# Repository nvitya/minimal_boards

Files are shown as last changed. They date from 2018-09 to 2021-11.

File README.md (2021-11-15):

# Breadboard Friendly Minimal Boards

The project on the Github: [https://github.com/nvitya/minimal_boards](https://github.com/nvitya/minimal_boards)

The boards are developed with KiCAD 5: [http://kicad.org/](http://kicad.org/)

## Board List

__Name__        | __Status__      | __Description__
----------------|-----------------|-------------------------------------------------------------
MIBO48-STM32    | Tested, OK      | For 48 pin QFP STM32 Microcontrollers (F103, F303, F070 etc)
MIBO48-STM32G4  | Tested, OK      | For 48 pin QFP STM32G4 Microcontrollers
MIBO48-XMC4     | Tested, OK      | For 48 pin QFP XMC4000 Microcontrollers
MIBO64-STM32    | Tested, OK      | For 64 pin QFP STM32 Microcontrollers (F405, F303, F070 etc)
MIBO64-ATSAM4S  | Tested, OK      | For 64 pin QFP ATSAM4SxB Microcontrollers
MIBO64-ATSAME5X | Tested, OK      | For 64 pin QFP ATSAME5xJ/ATSAMD5x Microcontrollers
MIBO20-STM32    | Tested, OK      | For the 20 pin TSSOP STM32 Microcontrollers (F030, F070, L011 etc)

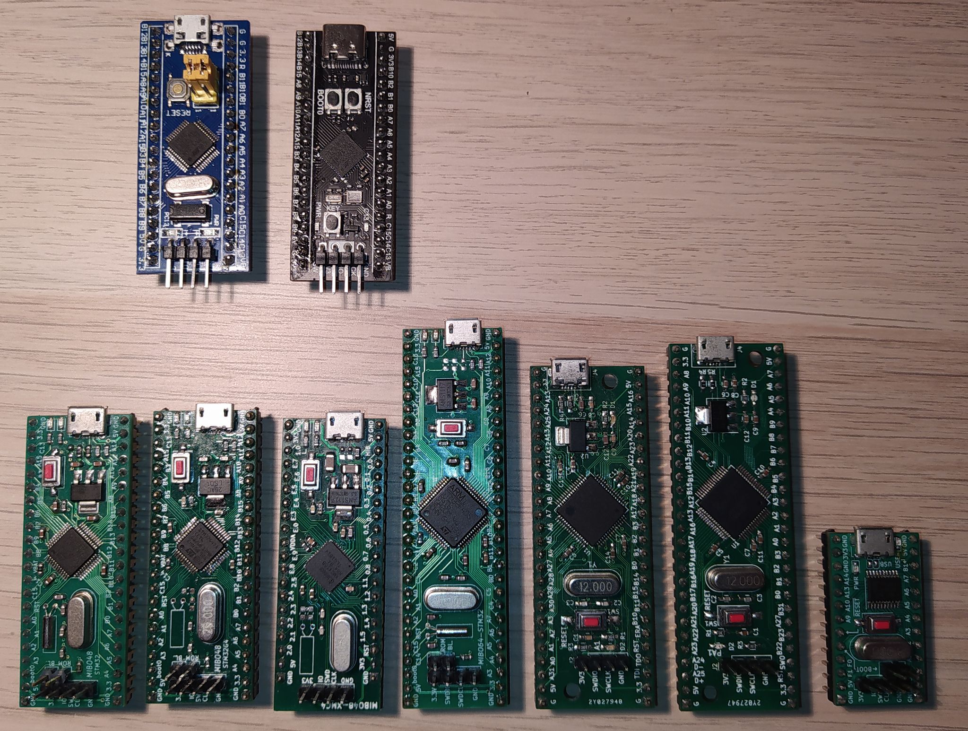
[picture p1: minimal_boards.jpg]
assembled boards


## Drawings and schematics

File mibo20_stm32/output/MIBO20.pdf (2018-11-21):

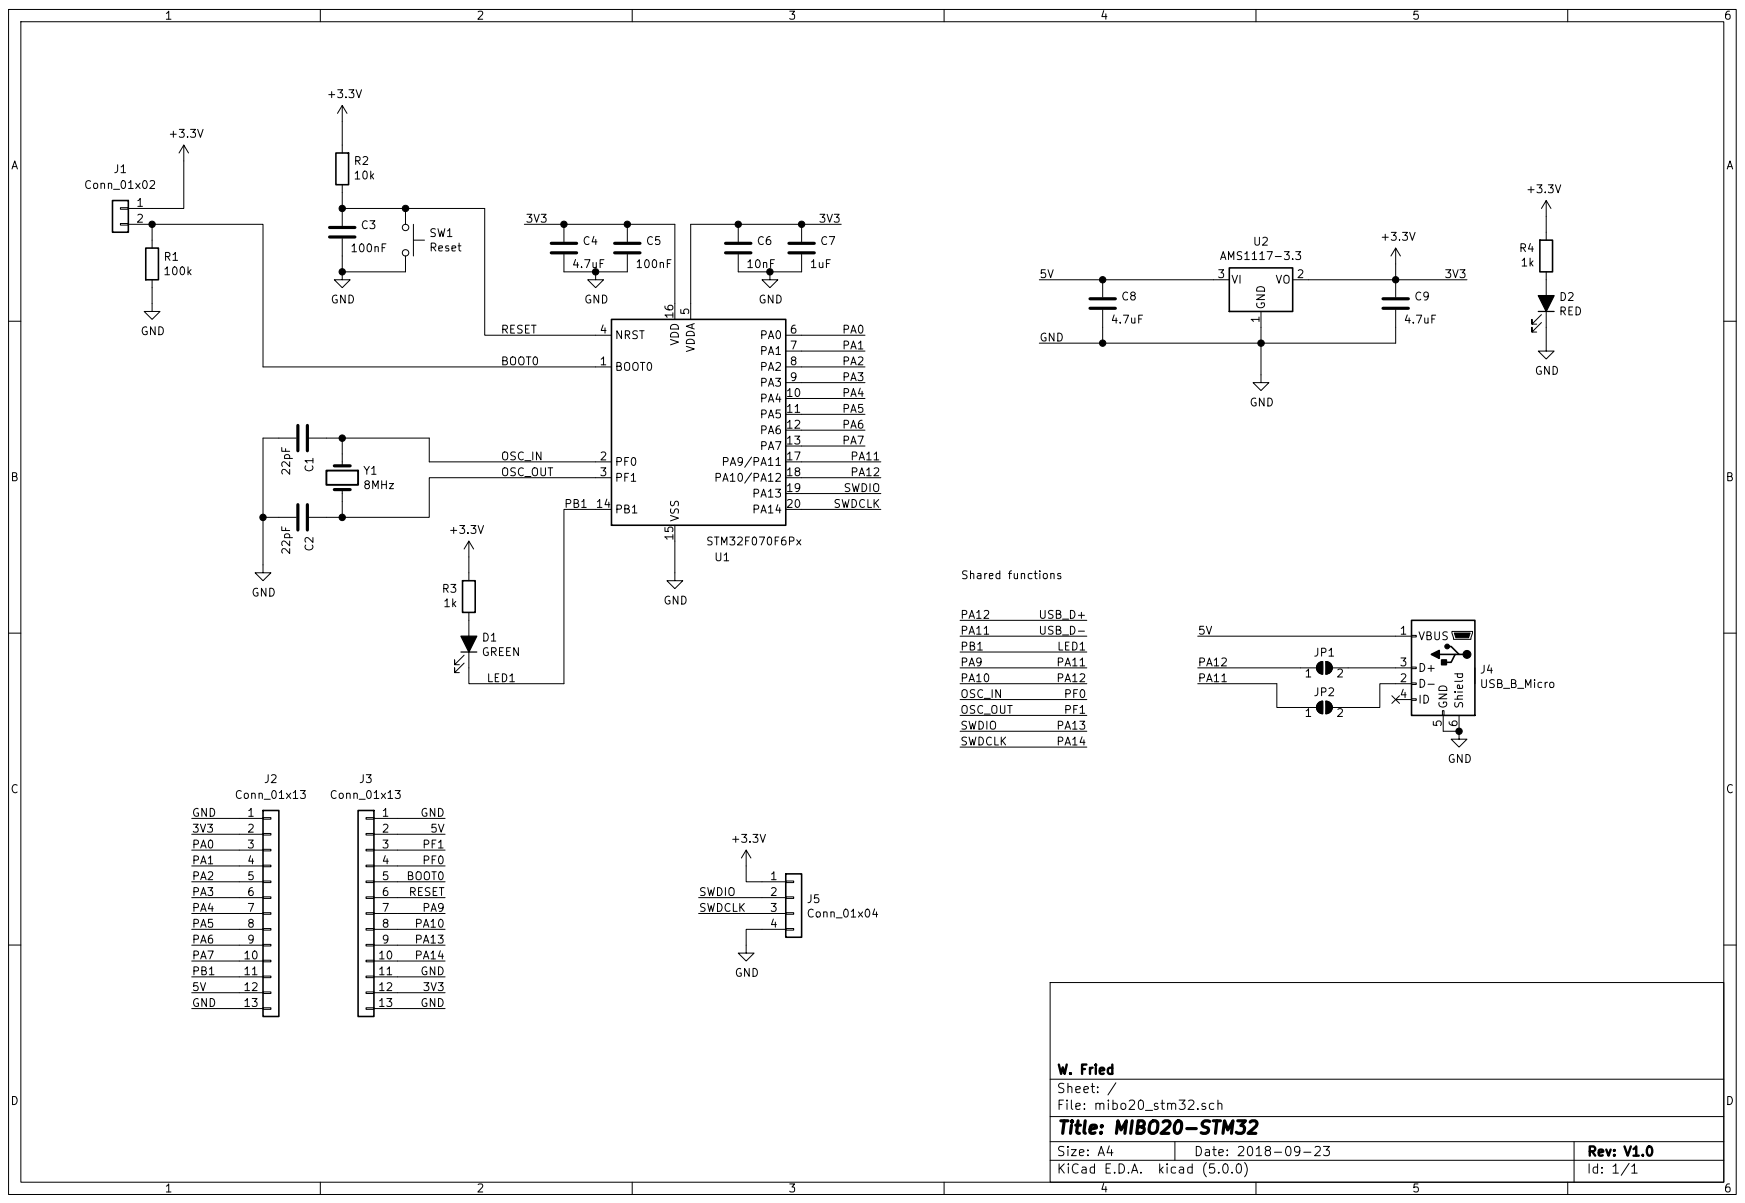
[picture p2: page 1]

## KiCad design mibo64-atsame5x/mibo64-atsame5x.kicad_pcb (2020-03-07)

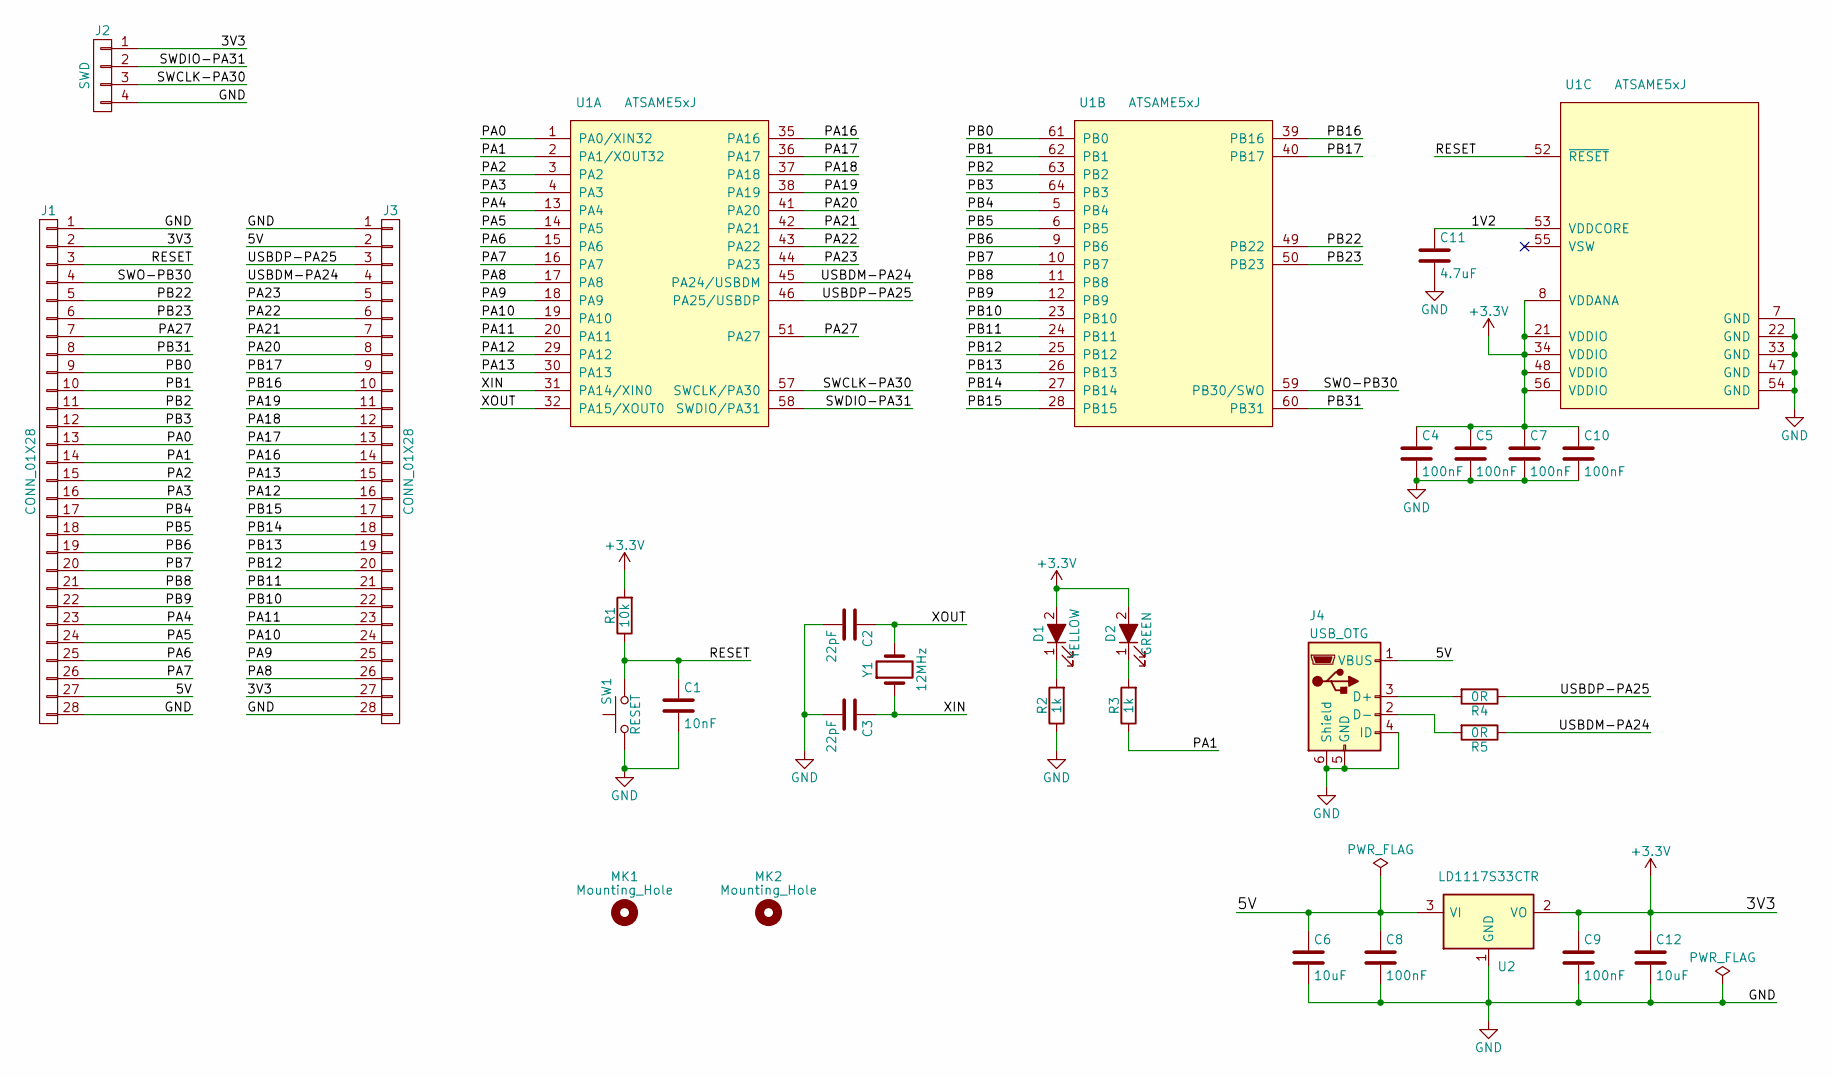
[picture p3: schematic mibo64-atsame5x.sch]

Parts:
C1: 10nF; C_0603_HandSoldering
C2, C3: 22pF; C_0603_HandSoldering
C4, C5, C7, C8, C9, C10: 100nF; C_0603_HandSoldering
C6, C12: 10uF; C_0603_HandSoldering
C11: 4.7uF; C_0603_HandSoldering
D1: YELLOW; LED_0603_HandSoldering
D2: GREEN; LED_0603_HandSoldering
J1, J3: CONN_01X28; Pin_Header_Straight_1x28_Pitch2.54mm
J2: SWD; Pin_Header_Straight_1x04_Pitch2.54mm
J4: USB_OTG; USB_Micro-B
MK1, MK2: Mounting_Hole; MountingHole_3.2mm_M3
R1: 10k; R_0603_HandSoldering
R2, R3: 1k; R_0603_HandSoldering
R4, R5: 0R; R_0603_HandSoldering
SW1: RESET; SW_SPST_FSMSM
U1: ATSAME5xJ; TQFP-64_10x10mm_Pitch0.5mm
U2: LD1117S33CTR; SOT-223
Y1: 12MHz; Crystal_HC49-4H_Vertical

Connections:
+3V3: C4.1, C5.1, C7.1, C9.1, C10.1, C12.1, D1.2 (A), D2.2 (A), J1.2, J2.1, J3.27, R1.2, U1.8 (VDDANA), U1.21 (VDDIO), U1.34 (VDDIO), U1.48 (VDDIO), U1.56 (VDDIO), U2.2 (VO)
/1V2: C11.1, U1.53 (VDDCORE)
/5V: C6.1, C8.1, J1.27, J3.2, J4.1 (VBUS), U2.3 (VI)
/PA0: J1.13, U1.1 (PA0/XIN32)
/PA1: J1.14, R3.1, U1.2 (PA1/XOUT32)
/PA2: J1.15, U1.3 (PA2)
/PA3: J1.16, U1.4 (PA3)
/PA4: J1.23, U1.13 (PA4)
/PA5: J1.24, U1.14 (PA5)
/PA6: J1.25, U1.15 (PA6)
/PA7: J1.26, U1.16 (PA7)
/PA8: J3.26, U1.17 (PA8)
/PA9: J3.25, U1.18 (PA9)
/PA10: J3.24, U1.19 (PA10)
/PA11: J3.23, U1.20 (PA11)
/PA12: J3.16, U1.29 (PA12)
/PA13: J3.15, U1.30 (PA13)
/PA16: J3.14, U1.35 (PA16)
/PA17: J3.13, U1.36 (PA17)
/PA18: J3.12, U1.37 (PA18)
/PA19: J3.11, U1.38 (PA19)
/PA20: J3.8, U1.41 (PA20)
/PA21: J3.7, U1.42 (PA21)
/PA22: J3.6, U1.43 (PA22)
/PA23: J3.5, U1.44 (PA23)
/PA27: J1.7, U1.51 (PA27)
/PB0: J1.9, U1.61 (PB0)
/PB1: J1.10, U1.62 (PB1)
/PB2: J1.11, U1.63 (PB2)
/PB3: J1.12, U1.64 (PB3)
/PB4: J1.17, U1.5 (PB4)
/PB5: J1.18, U1.6 (PB5)
/PB6: J1.19, U1.9 (PB6)
/PB7: J1.20, U1.10 (PB7)
/PB8: J1.21, U1.11 (PB8)
/PB9: J1.22, U1.12 (PB9)
/PB10: J3.22, U1.23 (PB10)
/PB11: J3.21, U1.24 (PB11)
/PB12: J3.20, U1.25 (PB12)
/PB13: J3.19, U1.26 (PB13)
/PB14: J3.18, U1.27 (PB14)
/PB15: J3.17, U1.28 (PB15)
/PB16: J3.10, U1.39 (PB16)
/PB17: J3.9, U1.40 (PB17)
/PB22: J1.5, U1.49 (PB22)
/PB23: J1.6, U1.50 (PB23)
/PB31: J1.8, U1.60 (PB31)
/RESET: C1.1, J1.3, R1.1, SW1.2, U1.52 (~RESET)
/SWCLK-PA30: J2.3, U1.57 (SWCLK/PA30)
/SWDIO-PA31: J2.2, U1.58 (SWDIO/PA31)
/SWO-PB30: J1.4, U1.59 (PB30/SWO)
/USBDM-PA24: J3.4, R5.1, U1.45 (PA24/USBDM)
/USBDP-PA25: J3.3, R4.1, U1.46 (PA25/USBDP)
/XIN: C3.1, U1.31 (PA14/XIN0), Y1.1
/XOUT: C2.1, U1.32 (PA15/XOUT0), Y1.2
GND: C1.2, C2.2, C3.2, C4.2, C5.2, C6.2, C7.2, C8.2, C9.2, C10.2, C11.2, C12.2, J1.1, J1.28, J2.4, J3.1, J3.28, J4.4 (ID), J4.5 (GND), J4.6 (Shield), R2.1, SW1.1, U1.7 (GND), U1.22 (GND), U1.33 (GND), U1.47 (GND), U1.54 (GND), U2.1 (GND)
unnamed: D1.1 (K), R2.2
unnamed: D2.1 (K), R3.2
unnamed: J4.2 (D-), R5.2
unnamed: J4.3 (D+), R4.2

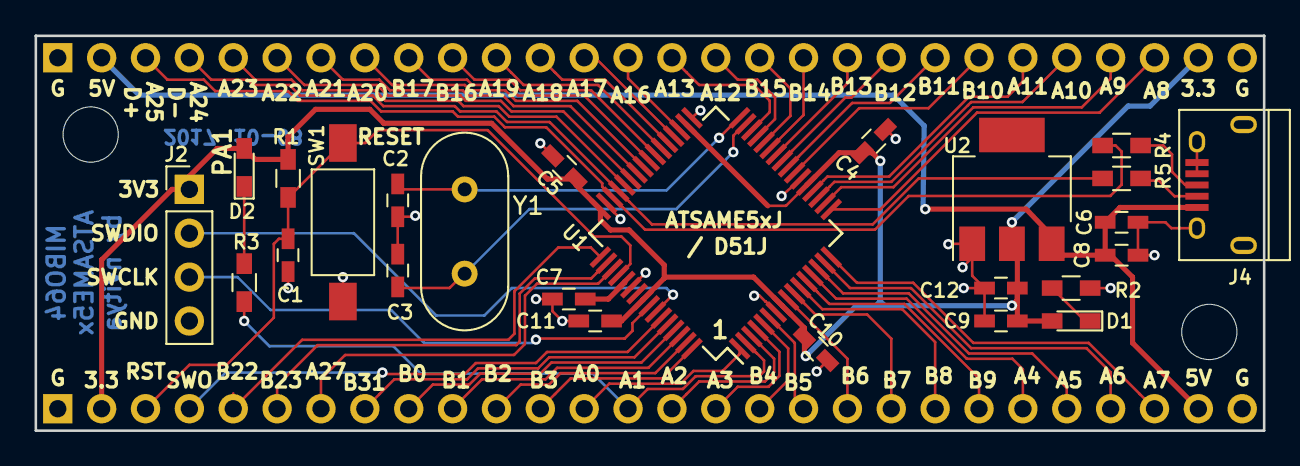
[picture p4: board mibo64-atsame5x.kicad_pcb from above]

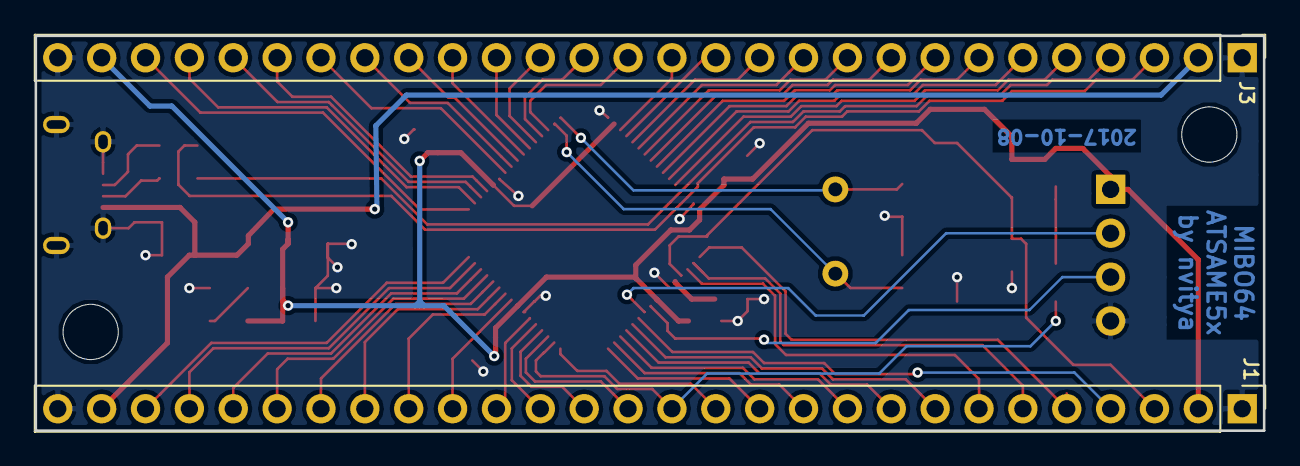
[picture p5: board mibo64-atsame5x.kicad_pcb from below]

Board: 2 copper layers, 71.1 x 22.9 mm, 29 parts (2 on the bottom side), 60 nets.

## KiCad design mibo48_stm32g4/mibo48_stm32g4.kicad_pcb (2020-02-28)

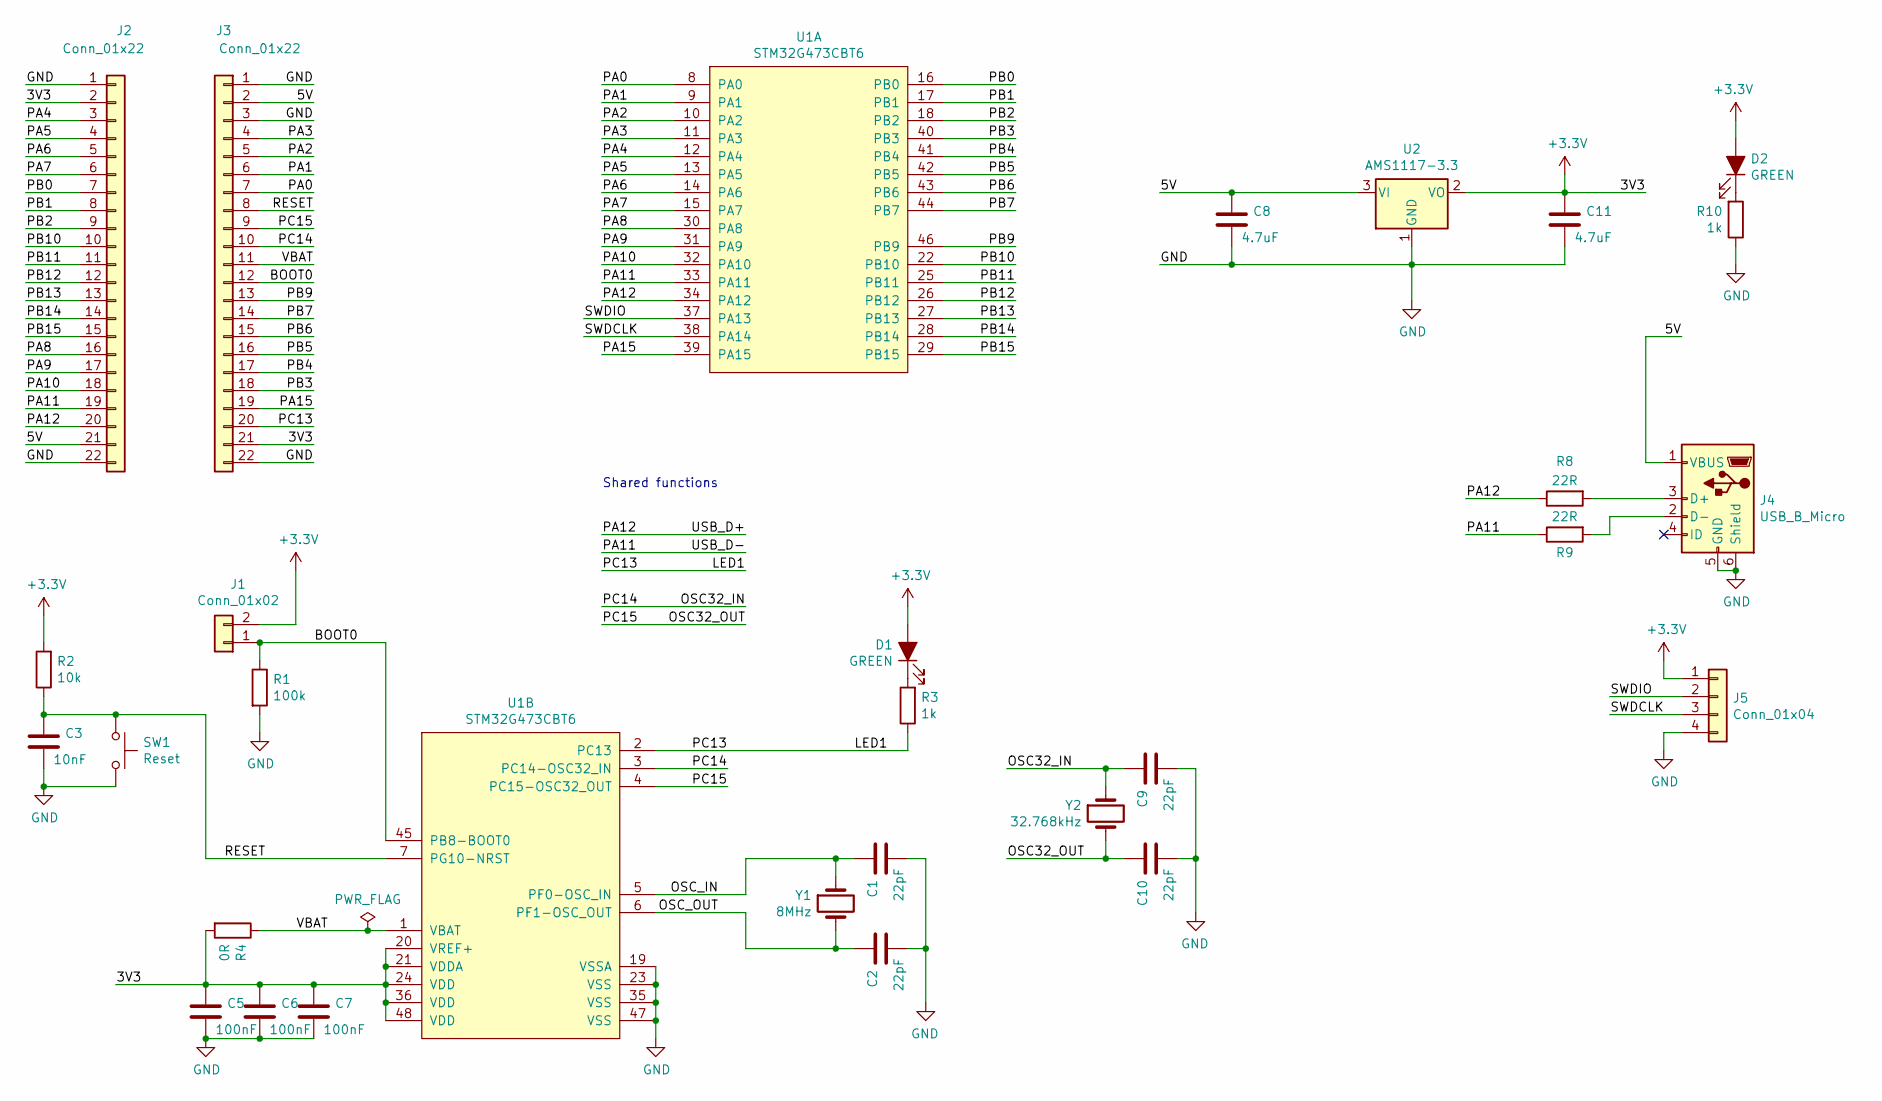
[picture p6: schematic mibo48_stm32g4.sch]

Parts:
C1, C2, C9, C10: 22pF; C_0603_1608Metric
C3: 10nF; C_0603_1608Metric
C5, C6, C7: 100nF; C_0603_1608Metric
C8, C11: 4.7uF; C_0603_1608Metric
D1, D2: GREEN; LED_0603_1608Metric
J1: Conn_01x02; PinHeader_1x02_P2.54mm_Vertical
J2, J3: Conn_01x22; PinHeader_1x22_P2.54mm_Vertical
J4: USB_B_Micro; USB_Micro-B_Molex-105017-0001
J5: Conn_01x04; PinHeader_1x04_P2.54mm_Vertical
R1: 100k; R_0603_1608Metric
R2: 10k; R_0603_1608Metric
R3, R10: 1k; R_0603_1608Metric
R4: 0R; R_0603_1608Metric
R8, R9: 22R; R_0603_1608Metric
SW1: Reset; SW_SPST_CK_RS282G05A3
U1: STM32G473CBT6; LQFP-48_7x7mm_P0.5mm
U2: AMS1117-3.3; SOT-223
Y1: 8MHz; Crystal_HC49-4H_Vertical
Y2: 32.768kHz; Crystal_C26-LF_D2.1mm_L6.5mm_Horizontal

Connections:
+3V3: C5.1, C6.1, C7.1, C11.1, D1.2 (A), D2.2 (A), J1.2, J2.2, J3.21, J5.1, R2.2, R4.2, U1.20 (VREF+), U1.21 (VDDA), U1.24 (VDD), U1.36 (VDD), U1.48 (VDD), U2.2 (VO)
/5V: C8.1, J2.21, J3.2, J4.1 (VBUS), U2.3 (VI)
/BOOT0: J1.1, J3.12, R1.1, U1.45 (PB8-BOOT0)
/LED1: J3.20, R3.1, U1.2 (PC13)
/OSC32_IN: C9.1, J3.10, U1.3 (PC14-OSC32_IN), Y2.1
/OSC32_OUT: C10.1, J3.9, U1.4 (PC15-OSC32_OUT), Y2.2
/OSC_IN: C1.1, U1.5 (PF0-OSC_IN), Y1.1
/OSC_OUT: C2.1, U1.6 (PF1-OSC_OUT), Y1.2
/PA0: J3.7, U1.8 (PA0)
/PA1: J3.6, U1.9 (PA1)
/PA2: J3.5, U1.10 (PA2)
/PA3: J3.4, U1.11 (PA3)
/PA4: J2.3, U1.12 (PA4)
/PA5: J2.4, U1.13 (PA5)
/PA6: J2.5, U1.14 (PA6)
/PA7: J2.6, U1.15 (PA7)
/PA8: J2.16, U1.30 (PA8)
/PA9: J2.17, U1.31 (PA9)
/PA10: J2.18, U1.32 (PA10)
/PA11: J2.19, R9.1, U1.33 (PA11)
/PA12: J2.20, R8.1, U1.34 (PA12)
/PA15: J3.19, U1.39 (PA15)
/PB0: J2.7, U1.16 (PB0)
/PB1: J2.8, U1.17 (PB1)
/PB2: J2.9, U1.18 (PB2)
/PB3: J3.18, U1.40 (PB3)
/PB4: J3.17, U1.41 (PB4)
/PB5: J3.16, U1.42 (PB5)
/PB6: J3.15, U1.43 (PB6)
/PB7: J3.14, U1.44 (PB7)
/PB9: J3.13, U1.46 (PB9)
/PB10: J2.10, U1.22 (PB10)
/PB11: J2.11, U1.25 (PB11)
/PB12: J2.12, U1.26 (PB12)
/PB13: J2.13, U1.27 (PB13)
/PB14: J2.14, U1.28 (PB14)
/PB15: J2.15, U1.29 (PB15)
/RESET: C3.1, J3.8, R2.1, SW1.1, U1.7 (PG10-NRST)
/SWDCLK: J5.3, U1.38 (PA14)
/SWDIO: J5.2, U1.37 (PA13)
/VBAT: J3.11, R4.1, U1.1 (VBAT)
GND: C1.2, C2.2, C3.2, C5.2, C6.2, C7.2, C8.2, C9.2, C10.2, C11.2, J2.1, J2.22, J3.1, J3.3, J3.22, J4.5 (GND), J4.6 (Shield), J5.4, R1.2, R10.1, SW1.2, U1.19 (VSSA), U1.23 (VSS), U1.35 (VSS), U1.47 (VSS), U2.1 (GND)
unnamed: D1.1 (K), R3.2
unnamed: D2.1 (K), R10.2
unnamed: J4.2 (D-), R9.2
unnamed: J4.3 (D+), R8.2

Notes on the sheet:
Shared functions

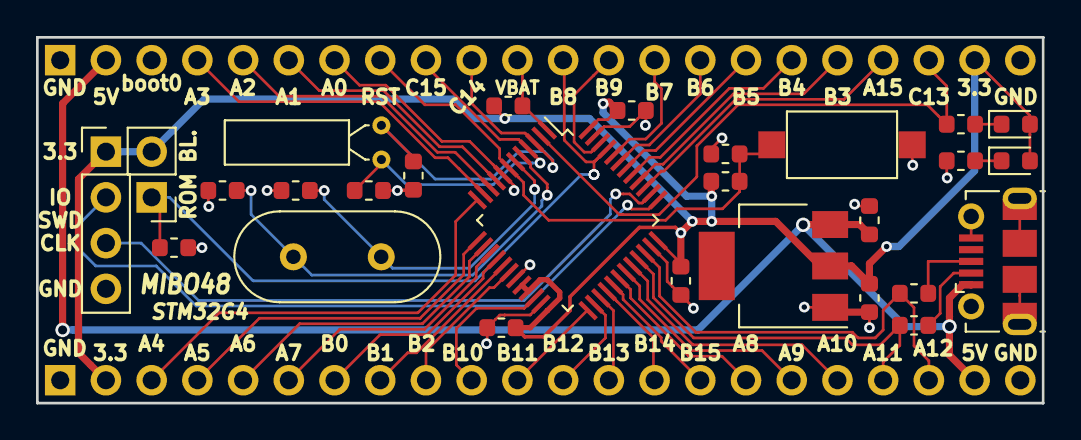
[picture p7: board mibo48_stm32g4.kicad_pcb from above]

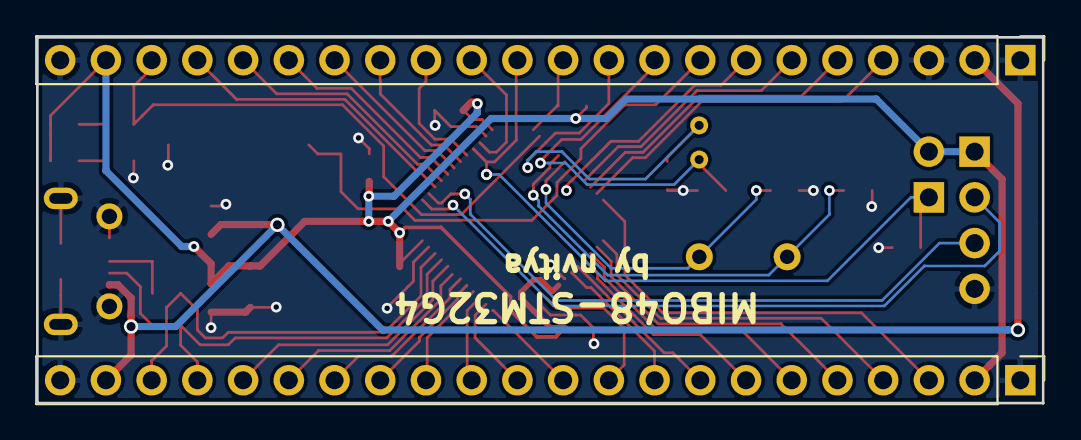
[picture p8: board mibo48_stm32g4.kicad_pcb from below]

Board: 2 copper layers, 55.9 x 20.3 mm, 29 parts (2 on the bottom side), 46 nets.

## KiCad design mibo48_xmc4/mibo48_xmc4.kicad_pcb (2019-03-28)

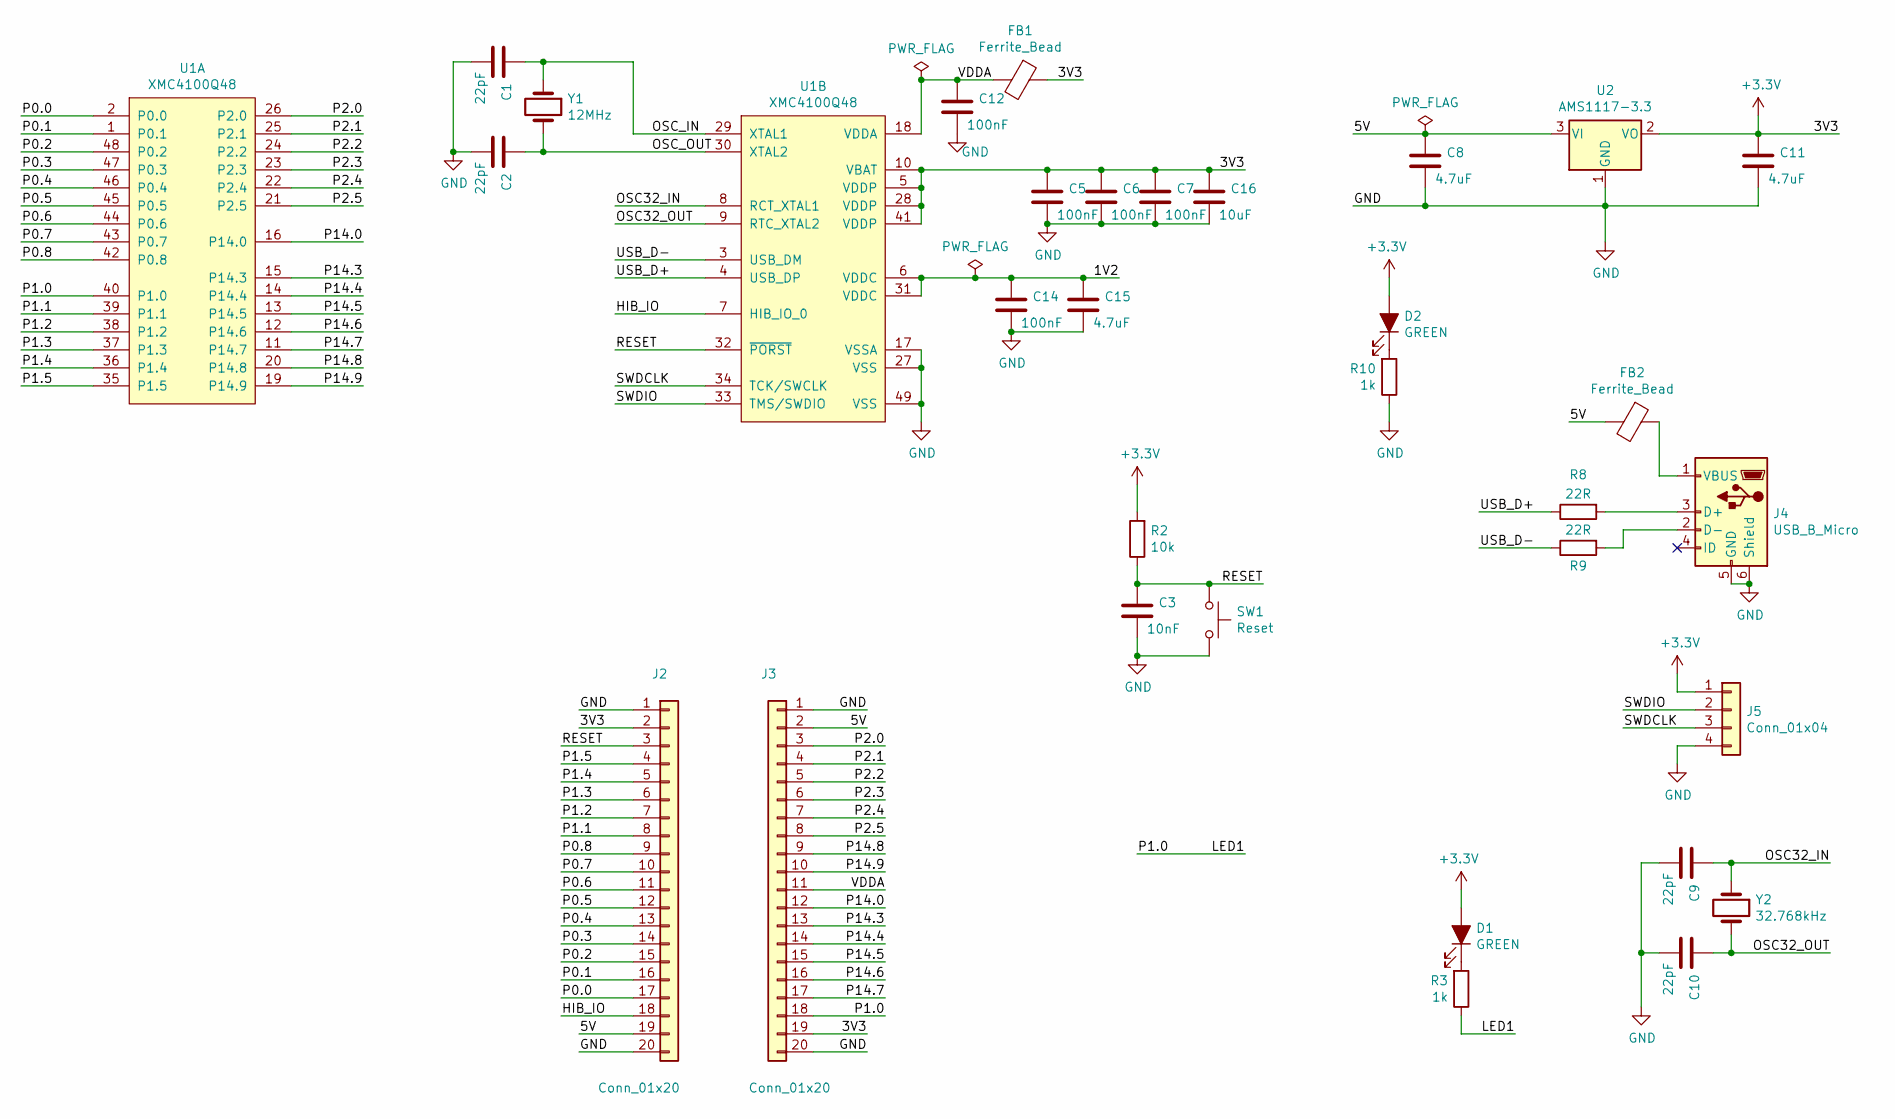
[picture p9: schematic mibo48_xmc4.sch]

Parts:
C1, C2, C9, C10: 22pF; C_0603_1608Metric
C3: 10nF; C_0603_1608Metric
C5, C6, C7, C12, C14: 100nF; C_0603_1608Metric
C8, C11: 4.7uF; C_1206_3216Metric
C15: 4.7uF; C_0603_1608Metric
C16: 10uF; C_0603_1608Metric
D1, D2: GREEN; LED_0603_1608Metric
FB1, FB2: Ferrite_Bead; L_0603_1608Metric
J2, J3: Conn_01x20; PinHeader_1x20_P2.54mm_Vertical
J4: USB_B_Micro; USB_Micro-B_Molex-105017-0001
J5: Conn_01x04; PinHeader_1x04_P2.54mm_Vertical
R2: 10k; R_0603_1608Metric
R3, R10: 1k; R_0603_1608Metric
R8, R9: 22R; R_0603_1608Metric
SW1: Reset; SW_SPST_CK_RS282G05A3
U1: XMC4100Q48; QFN-48-1EP_7x7mm_P0.5mm_EP5.3x5.3mm
U2: AMS1117-3.3; SOT-223-3_TabPin2
Y1: 12MHz; Crystal_HC49-4H_Vertical
Y2: 32.768kHz; Crystal_C26-LF_D2.1mm_L6.5mm_Horizontal

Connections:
+3V3: C5.1, C6.1, C7.1, C11.1, C16.1, D1.2 (A), D2.2 (A), FB1.1, J2.2, J3.19, J5.1, R2.2, U1.5 (VDDP), U1.10 (VBAT), U1.28 (VDDP), U1.41 (VDDP), U2.2 (VO)
/1V2: C14.1, C15.1, U1.6 (VDDC), U1.31 (VDDC)
/5V: C8.1, FB2.2, J2.19, J3.2, U2.3 (VI)
/HIB_IO: J2.18, U1.7 (HIB_IO_0)
/LED1: J3.18, R3.1, U1.40 (P1.0)
/OSC32_IN: C9.1, U1.8 (RCT_XTAL1), Y2.1
/OSC32_OUT: C10.1, U1.9 (RTC_XTAL2), Y2.2
/OSC_IN: C1.1, U1.29 (XTAL1), Y1.1
/OSC_OUT: C2.1, U1.30 (XTAL2), Y1.2
/P0.0: J2.17, U1.2 (P0.0)
/P0.1: J2.16, U1.1 (P0.1)
/P0.2: J2.15, U1.48 (P0.2)
/P0.3: J2.14, U1.47 (P0.3)
/P0.4: J2.13, U1.46 (P0.4)
/P0.5: J2.12, U1.45 (P0.5)
/P0.6: J2.11, U1.44 (P0.6)
/P0.7: J2.10, U1.43 (P0.7)
/P0.8: J2.9, U1.42 (P0.8)
/P1.1: J2.8, U1.39 (P1.1)
/P1.2: J2.7, U1.38 (P1.2)
/P1.3: J2.6, U1.37 (P1.3)
/P1.4: J2.5, U1.36 (P1.4)
/P1.5: J2.4, U1.35 (P1.5)
/P2.0: J3.3, U1.26 (P2.0)
/P2.1: J3.4, U1.25 (P2.1)
/P2.2: J3.5, U1.24 (P2.2)
/P2.3: J3.6, U1.23 (P2.3)
/P2.4: J3.7, U1.22 (P2.4)
/P2.5: J3.8, U1.21 (P2.5)
/P14.0: J3.12, U1.16 (P14.0)
/P14.3: J3.13, U1.15 (P14.3)
/P14.4: J3.14, U1.14 (P14.4)
/P14.5: J3.15, U1.13 (P14.5)
/P14.6: J3.16, U1.12 (P14.6)
/P14.7: J3.17, U1.11 (P14.7)
/P14.8: J3.9, U1.20 (P14.8)
/P14.9: J3.10, U1.19 (P14.9)
/RESET: C3.1, J2.3, R2.1, SW1.1, U1.32 (~PORST)
/SWDCLK: J5.3, U1.34 (TCK/SWCLK)
/SWDIO: J5.2, U1.33 (TMS/SWDIO)
/USB_D+: R8.1, U1.4 (USB_DP)
/USB_D-: R9.1, U1.3 (USB_DM)
/VDDA: C12.1, FB1.2, J3.11, U1.18 (VDDA)
GND: C1.2, C2.2, C3.2, C5.2, C6.2, C7.2, C8.2, C9.2, C10.2, C11.2, C12.2, C14.2, C15.2, C16.2, J2.1, J2.20, J3.1, J3.20, J4.5 (GND), J4.6 (Shield), J5.4, R10.1, SW1.2, U1.17 (VSSA), U1.27 (VSS), U1.49 (VSS), U2.1 (GND)
unnamed: D1.1 (K), R3.2
unnamed: D2.1 (K), R10.2
unnamed: FB2.1, J4.1 (VBUS)
unnamed: J4.2 (D-), R9.2
unnamed: J4.3 (D+), R8.2

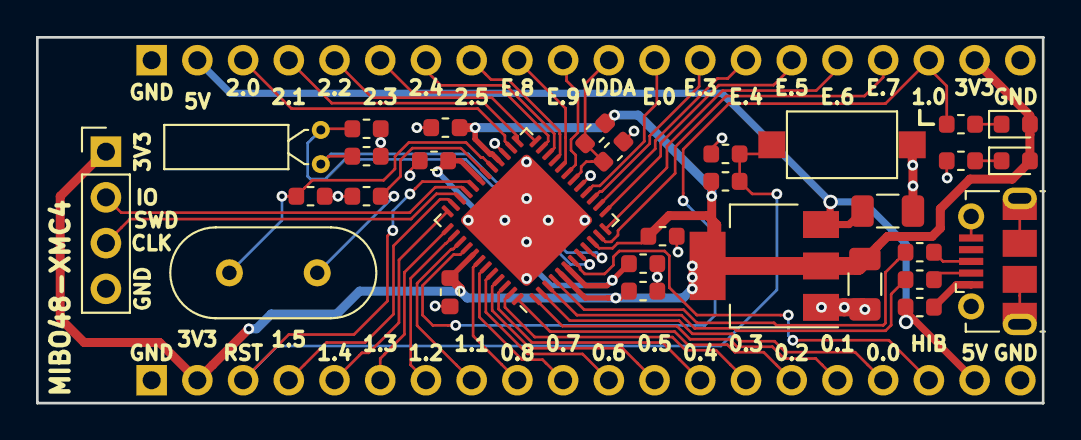
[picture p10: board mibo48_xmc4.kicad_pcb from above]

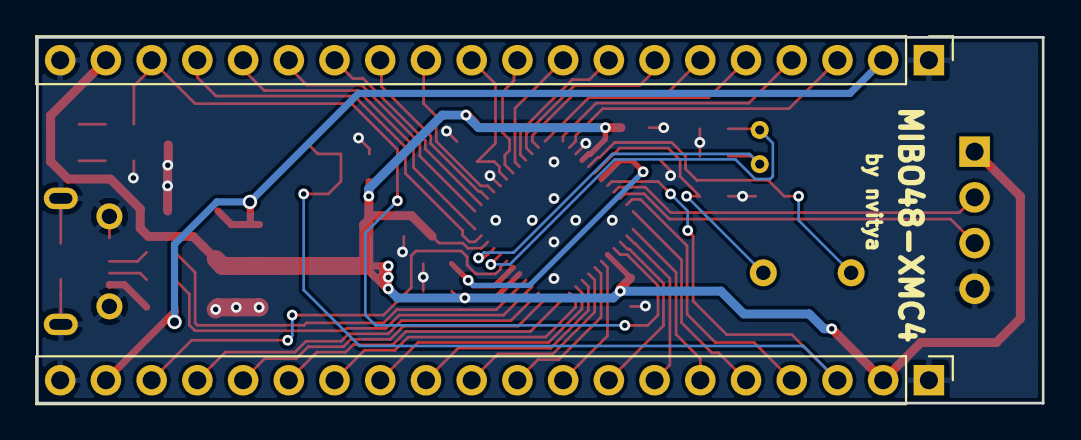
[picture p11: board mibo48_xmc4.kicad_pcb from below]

Board: 2 copper layers, 55.9 x 20.3 mm, 32 parts (2 on the bottom side), 49 nets.

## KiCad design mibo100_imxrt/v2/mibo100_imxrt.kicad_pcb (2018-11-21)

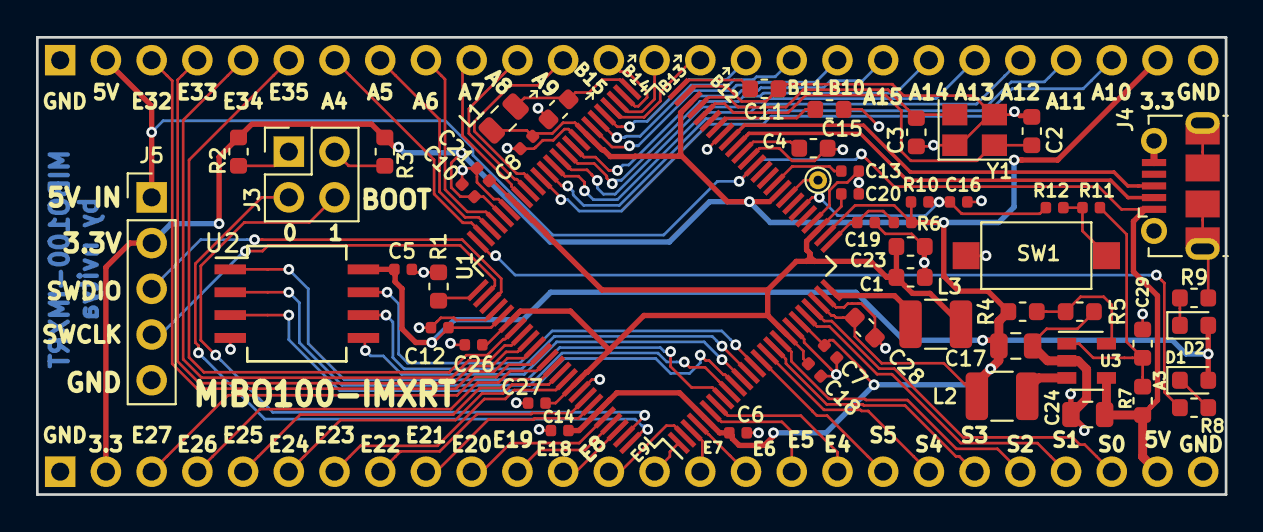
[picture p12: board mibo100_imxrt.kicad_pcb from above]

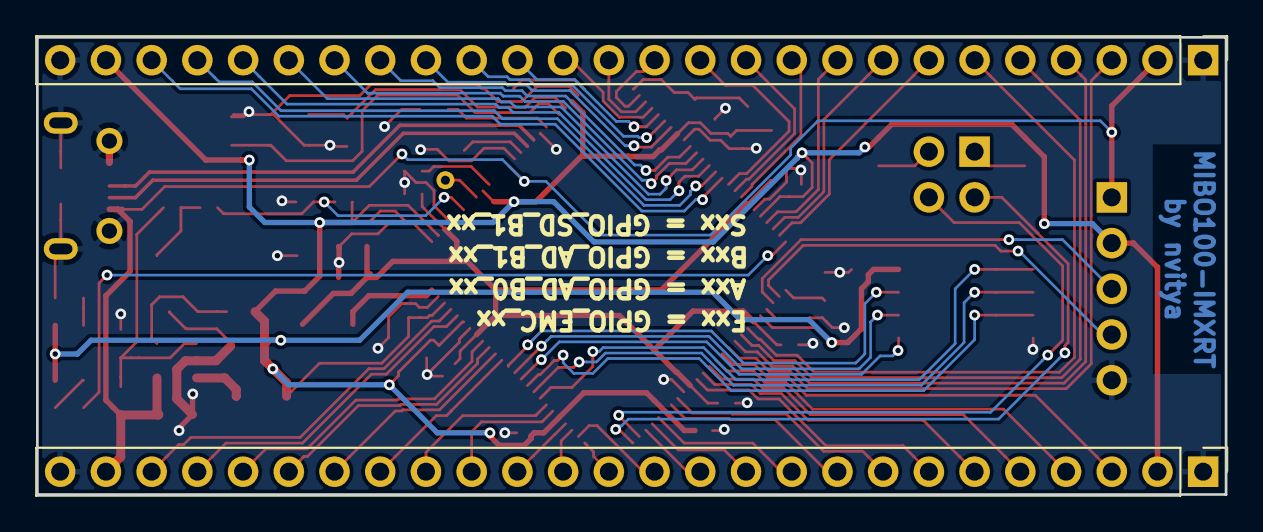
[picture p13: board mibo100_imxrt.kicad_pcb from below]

Board: 2 copper layers, 66.0 x 25.4 mm, 55 parts (2 on the bottom side), 81 nets.

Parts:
C1, C23: 22uF; C_0603_1608Metric
C2, C3: 22pF; C_0603_1608Metric
C4: 10uF; C_0603_1608Metric
C5, C6, C7, C8, C10, C12, C13, C14, C16, C18, C19, C20, C21, C26, C27: 220nF; C_0402_1005Metric
C9, C11, C15, C28: 4.7uF; C_0603_1608Metric
C17, C24: 4.7uF; C_0805_2012Metric
C29: 100nF; C_0603_1608Metric
D1, D2: GREEN; LED_0603_1608Metric
J1, J2: Conn_01x26; PinHeader_1x26_P2.54mm_Vertical
J3: Conn_02x02_Odd_Even; PinHeader_2x02_P2.54mm_Vertical
J4: USB_B_Micro; USB_Micro-B_Molex-105017-0001
J5: Conn_01x05; PinHeader_1x05_P2.54mm_Vertical
J6: Conn_01x01; TestPoint_THTPad_D1.0mm_Drill0.5mm
L1: 47nH; L_0805_2012Metric
L2: 2.2 uH; L_1210_3225Metric
L3: 4.7 uH; L_1210_3225Metric
R1, R2, R3, R7: 10k; R_0603_1608Metric
R4: 68k; R_0603_1608Metric
R5: 15k; R_0603_1608Metric
R6, R10: 30k; R_0402_1005Metric
R8, R9: 1k; R_0603_1608Metric
R11, R12: 0R; R_0402_1005Metric
SW1: SW_Push; SW_SPST_CK_RS282G05A3
U1: MIMXRT1021CAF4A; LQFP-100_14x14mm_P0.5mm
U2: W25X80; SO-8_5.3x6.2mm_P1.27mm
U3: AP3417C; SOT-23-5
Y1: 24MHz; Crystal_SMD_3225-4Pin_3.2x2.5mm

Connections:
+3V3: C5.1, C6.1, C7.1, C8.1, C10.1, C12.1, C14.1, C17.1, C28.1, D1.2, D2.2, J1.2, J2.25, J5.2, L1.1, L2.1, R2.2, R3.2, R4.2, R6.2, R10.2, U1.5, U1.20, U1.23, U1.27, U1.34, U1.48, U1.58, U1.71, U1.80, U1.95, U2.8
/3V3-EN: C29.1, R7.1, R11.1, U3.1
/5V: C24.1, J1.25, J2.2, J4.1, J5.1, R7.2, U1.38, U3.4
/A4: J2.7, U1.74
/A5: J2.8, U1.73
/A6: J2.9, U1.72
/A7: J2.10, U1.68
/A8: J2.11, U1.67
/A9: J2.12, U1.66
/A10: J2.24, U1.65
/A11: J2.23, U1.64
/A12: J2.22, U1.63
/A13: J2.21, U1.62
/A14: J2.20, U1.61
/A15: J2.19, U1.60
/B10: J2.18, U1.57
/B11: J2.17, U1.56
/B12: J2.16, U1.55
/B13: J2.15, U1.54
/B14: J2.14, U1.53
/B15: J2.13, U1.52
/BOOT-CFG-0: J3.3, U1.100
/BOOT-CFG-1: J3.4, U1.99
/DCDC_OUT: C1.1, C18.1, C20.1, C21.1, C23.1, C26.1, C27.1, L3.2, U1.18, U1.28, U1.69, U1.81, U1.91
/E4: J1.18, U1.7
/E5: J1.17, U1.6
/E6: J1.16, U1.4
/E7: J1.15, U1.3
/E8: J1.13, U1.2
/E9: J1.14, U1.1
/E18: J1.12, U1.98
/E19: J1.11, U1.97
/E20: J1.10, U1.96
/E21: J1.9, U1.94
/E22: J1.8, U1.93
/E23: J1.7, U1.90
/E24: J1.6, U1.89
/E25: J1.5, U1.88
/E26: J1.4, U1.87
/E27: J1.3, U1.86
/E32: J2.3, U1.85
/E33: J2.4, U1.84
/E34: J2.5, U1.83
/E35: J2.6, U1.82
/FLASH-CLK: U1.12, U2.6
/FLASH-CS: U1.8, U2.1
/FLASH-D0: U1.11, U2.5
/FLASH-D1: U1.9, U2.2
/FLASH-D2: U1.10, U2.3
/FLASH-D3: U1.13, U2.7
/JTAG-MOD: R1.2, U1.76
/LED1: R8.1, U1.75
/PMIC_ON: J6.1, U1.33
/POR_B: C16.1, R10.1, R12.2, U1.31
/S0: J1.24, U1.22
/S1: J1.23, U1.21
/S2: J1.22, U1.17
/S3: J1.21, U1.16
/S4: J1.20, U1.15
/S5: J1.19, U1.14
/SWDCLK: J5.4, U1.77
/SWDIO: J5.3, U1.78
/USB-D+: J4.3, U1.42
/USB-D-: J4.2, U1.41
/VDDA: C9.1, L1.2, U1.51
GND: C1.2, C2.2, C3.2, C4.2, C5.2, C6.2, C7.2, C8.2, C9.2, C10.2, C11.2, C12.2, C13.2, C14.2, C15.2, C16.2, C17.2, C18.2, C19.2, C20.2, C21.2, C23.2, C24.2, C26.2, C27.2, C28.2, C29.2, J1.1, J1.26, J2.1, J2.26, J4.5, J4.6, J5.5, R1.1, R5.1, R9.1, SW1.2, U1.19, U1.24, U1.29, U1.39, U1.43, U1.49, U1.59, U1.70, U1.79, U1.92, U2.4, U3.2, Y1.1, Y1.3
unnamed: C2.1, U1.46, Y1.2
unnamed: C3.1, U1.47, Y1.4
unnamed: C4.1, U1.40
unnamed: C11.1, U1.50
unnamed: C13.1, U1.35
unnamed: C15.1, U1.44
unnamed: C19.1, R6.1, U1.26
unnamed: D1.1, R8.2
unnamed: D2.1, R9.2
unnamed: J3.1, R2.1
unnamed: J3.2, R3.1
unnamed: L2.2, U3.3
unnamed: L3.1, U1.25
unnamed: R4.1, R5.2, U3.5
unnamed: R11.2, R12.1, SW1.1

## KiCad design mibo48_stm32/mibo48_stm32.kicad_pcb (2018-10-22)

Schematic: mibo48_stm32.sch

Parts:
C1, C2, C9, C10: 22pF; C_0603_1608Metric
C3: 10nF; C_0603_1608Metric
C4, C5, C6, C7: 100nF; C_0603_1608Metric
C8, C11: 4.7uF; C_0603_1608Metric
D1, D2: GREEN; LED_0603_1608Metric
J1: Conn_01x02; PinHeader_1x02_P2.54mm_Vertical
J2, J3: Conn_01x22; PinHeader_1x22_P2.54mm_Vertical
J4: USB_B_Micro; USB_Micro-B_Molex-105017-0001
J5: Conn_01x04; PinHeader_1x04_P2.54mm_Vertical
R1: 100k; R_0603_1608Metric
R2: 10k; R_0603_1608Metric
R3, R10: 1k; R_0603_1608Metric
R4, R5, R6: 0R; R_0603_1608Metric
R7: 1.5k; R_0603_1608Metric
R8, R9: 22R; R_0603_1608Metric
SW1: Reset; SW_SPST_CK_RS282G05A3
U1: STM32F303CBTx; LQFP-48_7x7mm_P0.5mm
U2: AMS1117-3.3; SOT-223
Y1: 8MHz; Crystal_HC49-4H_Vertical
Y2: 32.768kHz; Crystal_C26-LF_D2.1mm_L6.5mm_Horizontal

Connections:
+3V3: C4.1, C5.1, C6.1, C7.1, C11.1, D1.2, D2.2, J1.2, J2.2, J3.21, J5.1, R2.2, R4.2, U1.9, U1.24, U1.36, U1.48, U2.2 (VO)
/5V: C8.1, J2.21, J3.2, J4.1, R6.1, U2.3 (VI)
/BOOT0: J1.1, J3.3, R1.1, U1.44
/LED1: J3.20, R3.1, U1.2
/OSC32_IN: C9.1, J3.10, U1.3, Y2.1
/OSC32_OUT: C10.1, J3.9, U1.4, Y2.2
/OSC_IN: C1.1, U1.5, Y1.1
/OSC_OUT: C2.1, U1.6, Y1.2
/PA0: J3.7, U1.10
/PA1: J3.6, U1.11
/PA2: J3.5, U1.12
/PA3: J3.4, U1.13
/PA4: J2.3, U1.14
/PA5: J2.4, U1.15
/PA6: J2.5, U1.16
/PA7: J2.6, U1.17
/PA8: J2.16, U1.29
/PA9: J2.17, U1.30
/PA10: J2.18, U1.31
/PA11: J2.19, R9.1, U1.32
/PA12: J2.20, R8.1, U1.33
/PA15: J3.19, R5.2, U1.38
/PB0: J2.7, U1.18
/PB1: J2.8, U1.19
/PB2: J2.9, U1.20
/PB3: J3.18, U1.39
/PB4: J3.17, U1.40
/PB5: J3.16, U1.41
/PB6: J3.15, U1.42
/PB7: J3.14, U1.43
/PB8: J3.12, U1.45
/PB9: J3.13, U1.46
/PB10: J2.10, U1.21
/PB11: J2.11, U1.22
/PB12: J2.12, U1.25
/PB13: J2.13, U1.26
/PB14: J2.14, U1.27
/PB15: J2.15, U1.28
/RESET: C3.1, J3.8, R2.1, SW1.1, U1.7
/SWDCLK: J5.3, U1.37
/SWDIO: J5.2, U1.34
/VBAT: J3.11, R4.1, U1.1
GND: C1.2, C2.2, C3.2, C4.2, C5.2, C6.2, C7.2, C8.2, C9.2, C10.2, C11.2, J2.1, J2.22, J3.1, J3.22, J4.5, J4.6, J5.4, R1.2, R10.1, SW1.2, U1.8, U1.23, U1.35, U1.47, U2.1 (GND)
unnamed: D1.1, R3.2
unnamed: D2.1, R10.2
unnamed: J4.2, R9.2
unnamed: J4.3, R7.1, R8.2
unnamed: R5.1, R6.2, R7.2

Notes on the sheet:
Shared functions

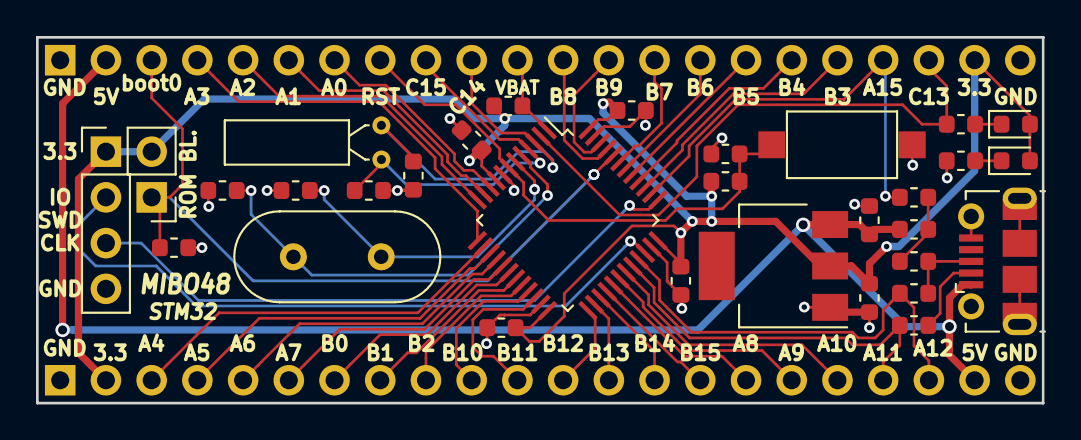
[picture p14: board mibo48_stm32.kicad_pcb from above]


Board: 2 copper layers, 55.9 x 20.3 mm, 33 parts (2 on the bottom side), 48 nets.

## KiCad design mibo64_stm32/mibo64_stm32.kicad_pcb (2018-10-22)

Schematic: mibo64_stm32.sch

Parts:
C1, C2, C9, C10: 22pF; C_0603_1608Metric
C3: 10nF; C_0603_1608Metric
C4, C5, C6, C7, C14: 100nF; C_0603_1608Metric
C8, C11: 4.7uF; C_0603_1608Metric
C12, C13: 2.2uF; C_0603_1608Metric
D1, D2: GREEN; LED_0603_1608Metric
J1: Conn_01x02; PinHeader_1x02_P2.54mm_Vertical
J2, J3: Conn_01x29; PinHeader_1x29_P2.54mm_Vertical
J4: USB_B_Micro; USB_Micro-B_Molex-105017-0001
J5: Conn_01x04; PinHeader_1x04_P2.54mm_Vertical
R1: 100k; R_0603_1608Metric
R2: 10k; R_0603_1608Metric
R3, R10: 1k; R_0603_1608Metric
R4, R5, R6: 0R; R_0603_1608Metric
R7: 1.5k; R_0603_1608Metric
R8, R9: 22R; R_0603_1608Metric
SW1: Reset; SW_SPST_CK_RS282G05A3
U1: STM32F405RGTx; LQFP-64_10x10mm_P0.5mm
U2: AMS1117-3.3; SOT-223
Y1: 8MHz; Crystal_HC49-4H_Vertical
Y2: 32.768kHz; Crystal_C26-LF_D2.1mm_L6.5mm_Horizontal

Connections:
+3V3: C4.1, C5.1, C6.1, C7.1, C11.1, C14.1, D1.2, D2.2, J1.2, J2.2, J3.28, J5.1, R2.2, R4.2, U1.13, U1.19, U1.32, U1.48, U1.64, U2.2 (VO)
/5V: C8.1, J2.28, J3.2, J4.1, R6.1, U2.3 (VI)
/BOOT0: J1.1, J3.3, R1.1, U1.60
/LED1: J3.27, R3.1, U1.2
/OSC32_IN: C9.1, J3.4, U1.3, Y2.1
/OSC32_OUT: C10.1, J3.5, U1.4, Y2.2
/OSC_IN: C1.1, U1.5, Y1.1
/OSC_OUT: C2.1, U1.6, Y1.2
/PA0: J3.9, U1.14
/PA1: J3.8, U1.15
/PA2: J3.7, U1.16
/PA3: J2.3, U1.17
/PA4: J2.4, U1.20
/PA5: J2.5, U1.21
/PA6: J2.6, U1.22
/PA7: J2.7, U1.23
/PA8: J2.23, U1.41
/PA9: J2.24, U1.42
/PA10: J2.25, U1.43
/PA11: J2.26, R9.1, U1.44
/PA12: J2.27, R8.1, U1.45
/PA15: J3.26, R5.2, U1.50
/PB0: J2.10, U1.26
/PB1: J2.11, U1.27
/PB2: J2.14, U1.28
/PB3: J3.21, U1.55
/PB4: J3.20, U1.56
/PB5: J3.19, U1.57
/PB6: J3.18, U1.58
/PB7: J3.17, U1.59
/PB8: J3.15, U1.61
/PB9: J3.16, U1.62
/PB10: J2.13, U1.29
/PB11: J2.12, U1.30
/PB12: J2.15, U1.33
/PB13: J2.16, U1.34
/PB14: J2.17, U1.35
/PB15: J2.18, U1.36
/PC0: J3.13, U1.8
/PC1: J3.12, U1.9
/PC2: J3.11, U1.10
/PC3: J3.10, U1.11
/PC4: J2.8, U1.24
/PC5: J2.9, U1.25
/PC6: J2.19, U1.37
/PC7: J2.20, U1.38
/PC8: J2.21, U1.39
/PC9: J2.22, U1.40
/PC10: J3.25, U1.51
/PC11: J3.24, U1.52
/PC12: J3.23, U1.53
/PD2: J3.22, U1.54
/RESET: C3.1, J3.6, R2.1, SW1.1, U1.7
/SWDCLK: J5.3, U1.49
/SWDIO: J5.2, U1.46
/VBAT: J3.14, R4.1, U1.1
GND: C1.2, C2.2, C3.2, C4.2, C5.2, C6.2, C7.2, C8.2, C9.2, C10.2, C11.2, C12.2, C13.2, C14.2, J2.1, J2.29, J3.1, J3.29, J4.5, J4.6, J5.4, R1.2, R10.1, SW1.2, U1.12, U1.18, U1.63, U2.1 (GND)
unnamed: C12.1, U1.31
unnamed: C13.1, U1.47
unnamed: D1.1, R3.2
unnamed: D2.1, R10.2
unnamed: J4.2, R9.2
unnamed: J4.3, R7.1, R8.2
unnamed: R5.1, R6.2, R7.2

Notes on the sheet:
Shared functions
0 Ohm resistors on F0,F1,F2,F3 devices



Board: 2 copper layers, 73.7 x 20.3 mm, 36 parts (2 on the bottom side), 64 nets.

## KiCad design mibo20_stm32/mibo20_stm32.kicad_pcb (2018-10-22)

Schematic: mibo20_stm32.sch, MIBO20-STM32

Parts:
C1, C2: 22pF; C_0603_1608Metric
C3, C5: 100nF; C_0603_1608Metric
C4, C8, C9: 4.7uF; C_0603_1608Metric
C6: 10nF; C_0603_1608Metric
C7: 1uF; C_0603_1608Metric
D1: GREEN; LED_0603_1608Metric
D2: RED; LED_0603_1608Metric
J1: Conn_01x02; PinHeader_1x02_P2.54mm_Vertical
J2, J3: Conn_01x13; PinHeader_1x13_P2.54mm_Vertical
J4: USB_B_Micro; USB_Micro-B_Molex-105017-0001
J5: Conn_01x04; PinHeader_1x04_P2.54mm_Vertical
JP1, JP2: SolderJumper_2_Open; SolderJumper-2_P0.8mm_Open_RoundedPad0.6x0.8mm
R1: 100k; R_0603_1608Metric
R2: 10k; R_0603_1608Metric
R3, R4: 1k; R_0603_1608Metric
SW1: Reset; SW_SPST_CK_RS282G05A3
U1: STM32F070F6Px; TSSOP-20_4.4x6.5mm_P0.65mm
U2: AMS1117-3.3; SOT-223
Y1: 8MHz; Crystal_HC49-4H_Vertical

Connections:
+3V3: C4.1, C5.1, C6.1, C7.1, C9.1, J1.1, J2.2, J3.12, J5.1, R2.2, R3.2, R4.2, U1.5, U1.16, U2.2 (VO)
/5V: C8.1, J2.12, J3.2, J4.1, U2.3 (VI)
/BOOT0: J1.2, J3.5, R1.1, U1.1
/LED1: D1.1, J2.11, U1.14
/OSC_IN: C1.1, J3.4, U1.2, Y1.1
/OSC_OUT: C2.1, J3.3, U1.3, Y1.2
/PA0: J2.3, U1.6
/PA1: J2.4, U1.7
/PA2: J2.5, U1.8
/PA3: J2.6, U1.9
/PA4: J2.7, U1.10
/PA5: J2.8, U1.11
/PA6: J2.9, U1.12
/PA7: J2.10, U1.13
/PA10: J3.8, JP1.1, U1.18
/PA11: J3.7, JP2.1, U1.17
/PA13: J3.9, J5.2, U1.19
/PA14: J3.10, J5.3, U1.20
/RESET: C3.1, J3.6, R2.1, SW1.1, U1.4
GND: C1.2, C2.2, C3.2, C4.2, C5.2, C6.2, C7.2, C8.2, C9.2, D2.1, J2.1, J2.13, J3.1, J3.11, J3.13, J4.5, J4.6, J5.4, R1.2, SW1.2, U1.15, U2.1 (GND)
unnamed: D1.2, R3.1
unnamed: D2.2, R4.1
unnamed: J4.2, JP2.2
unnamed: J4.3, JP1.2

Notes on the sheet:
Shared functions



Board: 2 copper layers, 33.0 x 17.8 mm, 26 parts (16 on the bottom side), 24 nets.

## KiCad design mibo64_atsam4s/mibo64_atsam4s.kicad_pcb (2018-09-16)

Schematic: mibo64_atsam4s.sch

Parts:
C1: 10nF; C_0603_HandSoldering
C2, C3: 22pF; C_0603_HandSoldering
C4, C5, C7, C8, C9, C13, C14: 100nF; C_0603_HandSoldering
C6, C12: 10uF; C_0603_HandSoldering
C10, C11: 1uF; C_0603_HandSoldering
D1: YELLOW; LED_0603_HandSoldering
D2: GREEN; LED_0603_HandSoldering
J1: EXT1; Pin_Header_Straight_1x26_Pitch2.54mm
J2: SWD; Pin_Header_Straight_1x04_Pitch2.54mm
J3: EXT2; Pin_Header_Straight_1x26_Pitch2.54mm
J4: USB_OTG; USB_Micro-B
MK1, MK2: Mounting_Hole; MountingHole_3.2mm_M3
R1: 10k; R_0603_HandSoldering
R2, R3: 1k; R_0603_HandSoldering
R4, R5: 22R; R_0603_HandSoldering
SW1: RESET; SW_SPST_FSMSM
U1: ATSAM4SxB; LQFP-64_10x10mm_Pitch0.5mm
U2: LD1117S33CTR; SOT-223
Y1: 12MHz; Crystal_HC49-4H_Vertical

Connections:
+3V3: C4.1, C5.1, C7.1, C9.1, C10.1, C12.1, D1.2, D2.2, J1.2, J2.1, J3.25, R1.2, U1.1 (ADVREF), U1.7 (VDDIN), U1.18 (VDDIO), U1.45 (VDDIO), U1.58 (VDDIO), U2.2 (VO)
/1V2: C11.1, C13.1, C14.1, U1.8 (VDDOUT), U1.12 (VDDCORE), U1.24 (VDDCORE), U1.54 (VDDCORE), U1.64 (VDDPLL)
/5V: C6.1, C8.1, J1.25, J3.2, J4.1 (VBUS), U2.3 (VI)
/ERASE-PB12: J1.6, U1.55 (ERASE/PB12)
/PA0: J3.4, U1.48 (PA0)
/PA1: J3.5, R3.1, U1.47 (PA1)
/PA2: J3.6, U1.44 (PA2)
/PA3: J3.7, U1.43 (PA3)
/PA4: J3.12, U1.36 (PA4)
/PA5: J3.13, U1.35 (PA5)
/PA6: J3.14, U1.34 (PA6)
/PA7: J3.15, U1.32 (PA7)
/PA8: J3.16, U1.31 (PA8)
/PA9: J3.17, U1.30 (PA9)
/PA10: J3.18, U1.29 (PA10)
/PA11: J3.19, U1.28 (PA11)
/PA12: J3.20, U1.27 (PA12)
/PA13: J3.24, U1.22 (PA13)
/PA14: J1.22, U1.21 (PA14)
/PA15: J1.23, U1.20 (PA15)
/PA16: J1.24, U1.19 (PA16)
/PA17: J1.15, U1.9 (PA17)
/PA18: J1.16, U1.10 (PA18)
/PA19: J1.18, U1.13 (PA19)
/PA20: J1.21, U1.16 (PA20)
/PA21: J1.17, U1.11 (PA21)
/PA22: J1.19, U1.14 (PA22)
/PA23: J1.20, U1.15 (PA23)
/PA24: J3.23, U1.23 (PA24)
/PA25: J3.22, U1.25 (PA25)
/PA26: J3.21, U1.26 (PA26)
/PA27: J3.11, U1.37 (PA27)
/PA28: J3.10, U1.38 (PA28)
/PA29: J3.9, U1.41 (PA29)
/PA30: J3.8, U1.42 (PA30)
/PA31: J3.3, U1.52 (PA31)
/PB0: J1.11, U1.3 (PB0/AD4)
/PB1: J1.12, U1.4 (PB1/AD5)
/PB2: J1.13, U1.5 (PB2/AD6)
/PB3: J1.14, U1.6 (PB3/AD7)
/PB13: J1.9, U1.59 (PB13/DAC0)
/PB14: J1.10, U1.63 (PB14/DAC1)
/RESET: C1.1, J1.5, R1.1, SW1.2, U1.39 (~RESET)
/SWCLK-PB7: J2.3, U1.53 (TCK/SWCLK/PB7)
/SWDIO-PB6: J2.2, U1.51 (TMS/SWDIO/PB6)
/TDI-PB4: J1.3, U1.33 (TDI/PB4)
/TDO-PB5: J1.4, U1.49 (TDO/SWO/PB5)
/USBDM-PB10: J1.7, R5.1, U1.56 (USBDM/PB10)
/USBDP-PB11: J1.8, R4.1, U1.57 (USBDP/PB11)
/XIN: C3.1, U1.62 (XIN/PB9), Y1.1
/XOUT: C2.1, U1.61 (XOUT/PB8), Y1.2
unnamed: D1.1, R2.2
unnamed: D2.1, R3.2
unnamed: J4.2 (D-), R5.2
unnamed: J4.3 (D+), R4.2

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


Board: 2 copper layers, 66.0 x 22.9 mm, 31 parts (2 on the bottom side), 56 nets.

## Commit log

2018-09-13 STM32F303Cx plan added, not ready yet
    [mibo48_stm32f303.kicad_pcb, mibo48_stm32f303.sch]
2018-09-15 - fully routed, only labelling is missing - kicad 5 project with new libraries and footprints
    [mibo48_stm32f303.kicad_pcb, mibo48_stm32f303.sch]
2018-09-15 project directory rename
    [mibo48_stm32f303.kicad_pcb, mibo48_stm32f303.sch]
2018-09-15 project renamed from STM32F303 to STM32
    [mibo48_stm32.kicad_pcb, mibo48_stm32.sch]
2018-09-15 draft of the 64 pin variant
    [mibo64_stm32.kicad_pcb, mibo64_stm32.sch]
2018-09-16 almost fully routed
    [mibo64_stm32.kicad_pcb, mibo64_stm32.sch]
2018-09-16 small layout change
    [mibo48_stm32.kicad_pcb]
2018-09-16 fully routed, labelling still missing
    [mibo64_stm32.kicad_pcb]
2018-09-16 imxrt1020 project added, MCU schematic symbol done
    [mibo100_imxrt.sch]
2018-09-16 Old ATSAM4S project added
    [mibo64_atsam4s.kicad_pcb, mibo64_atsam4s.sch]
2018-09-17 mibo20 stm32 project created
    [mibo20_stm32.kicad_pcb, mibo20_stm32.sch]
2018-09-22 Test commit
    [mibo20_stm32.kicad_pcb, mibo20_stm32.sch]
2018-09-23 V1.0 - Fully routed with description
    [mibo20_stm32.kicad_pcb, mibo20_stm32.sch]
2018-09-23 MIBO20-STM32 added
2018-09-23 small trace tweak
    [mibo20_stm32.kicad_pcb]
2018-09-23 added version to pcb
    [mibo20_stm32.kicad_pcb, mibo20_stm32.sch]
2018-09-23 MIBO48 Labelling finished
    [mibo48_stm32.kicad_pcb]
2018-09-23 MIBO64-STM32 finished.
    [mibo64_stm32.kicad_pcb]
2018-09-23 SWD connector rotated
    [mibo20_stm32.kicad_pcb]
2018-09-29 Q1 and SW1 swapped
    [mibo20_stm32.kicad_pcb, mibo20_stm32.sch]
2018-09-30 Jumper for USB added
    [mibo20_stm32.kicad_pcb, mibo20_stm32.sch]
2018-10-14 some progress with the imxrt
    [mibo100_imxrt.kicad_pcb, mibo100_imxrt.sch]
2018-10-20 routing finished
    [mibo100_imxrt.kicad_pcb, mibo100_imxrt.sch]
2018-10-21 captioning finished as well
    [mibo100_imxrt.kicad_pcb]
2018-10-21 gerber files generated
    [mibo100_imxrt-B.Cu.gbl, mibo100_imxrt-B.Mask.gbs, mibo100_imxrt-B.SilkS.gbo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]
2018-10-21 gerber files added
    [mibo20_stm32-B.Cu.gbl, mibo20_stm32-B.Mask.gbs, mibo20_stm32-B.SilkS.gbo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]
2018-10-21 gerber settings
    [mibo64_stm32.kicad_pcb]
2018-10-22 POR_B and double capacitors
    [mibo100_imxrt-B.Cu.gbl, mibo100_imxrt-B.Mask.gbs, mibo100_imxrt-B.SilkS.gbo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]
2018-10-22 board measurements added
    [mibo100_imxrt.kicad_pcb, mibo20_stm32.kicad_pcb, mibo48_stm32.kicad_pcb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]
2018-11-16 board status update
2018-11-21 version 2 created
    [mibo100_imxrt-B.Cu.gbl, mibo100_imxrt-B.Mask.gbs, mibo100_imxrt-B.SilkS.gbo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]
2019-03-27 mibo48-xmc4 routing finished
    [mibo48_xmc4.kicad_pcb, mibo48_xmc4.sch]
2019-03-28 captioned, gerbers
    [mibo48_xmc4-B.Cu.gbl, mibo48_xmc4-B.Mask.gbs, mibo48_xmc4-B.SilkS.gbo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]
2021-11-10 Update README.md
    https://forum.kicad.info/t/warning-avoid-all-links-to-kicad-pcb-org-use-kicad-org/31521
